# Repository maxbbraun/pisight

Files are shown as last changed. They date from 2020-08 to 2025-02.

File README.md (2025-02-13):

# PiSight

I put a Raspberry Pi inside an Apple iSight. You can read more about the PiSight [on Medium](https://pisight.camera).

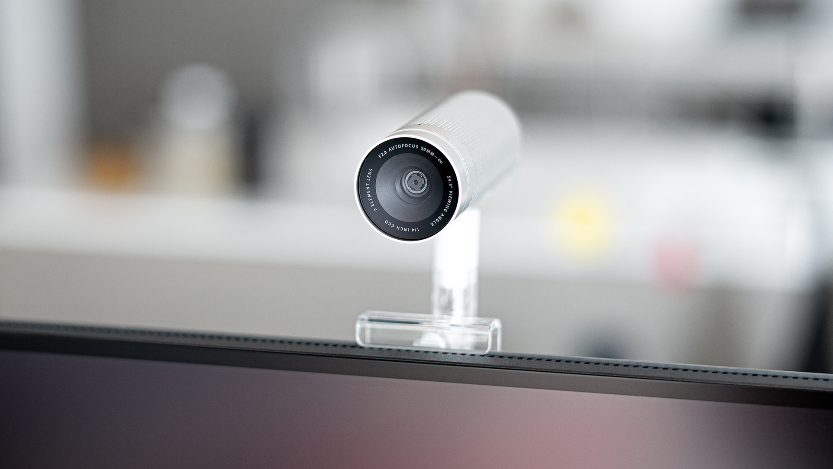
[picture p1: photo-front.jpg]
PiSight photo front view


## Hardware

| Part | Info | Price (2020) |
| :- | :- | -: |
| [Apple iSight](http://www.minimallyminimal.com/blog/apple-isight) | Available new and used on eBay | [$15 to 150](https://www.ebay.com/sch/i.html?_nkw=Apple+iSight) |
| [Raspberry Pi Zero](https://www.raspberrypi.org/products/raspberry-pi-zero/) | The [W](https://www.raspberrypi.org/products/raspberry-pi-zero-w/) version adds Wifi, which makes working with it easier and opens it up to more applications | [$5](https://www.adafruit.com/product/2885) or [$10](https://www.adafruit.com/product/3400) |
| [Raspberry Pi Camera V2](https://www.raspberrypi.org/products/camera-module-v2/) | Supports 1080p@30 or 720p@60, at a 62° horizontal field of view | [$29.95](https://www.adafruit.com/product/3099) |
| M2.6 screws | 4 of M2.6 x 0.45 mm Thread, 6 mm long | [$9.26 for 25](https://www.mcmaster.com/91290A073/) |
| M2 screws | 2 of M2 x 0.4 mm Thread, 4 mm long | [$13.28 for 100](https://www.mcmaster.com/91290A011/) |
| O-ring | Covers the gap around the lens | [$6.16 for 50](https://www.mcmaster.com/9262K562/) |
| Raspberry Pi Zero camera cable | A few options, but the 15 cm long narrow ones seem to work best | [$3.49](https://www.waveshare.com/raspberry-pi-zero-v1.3-camera-cable.htm) |
| Micro-USB cable | Many options, just need to fit the iSight adapter | [$8.99](https://www.amazon.com/Anker-Powerline-Micro-USB-Smartphones/dp/B012VZT5IO/) |
| 3D-printed frame | Use [`PiSight.stl`](PiSight.stl) or [`PiSight.step`](PiSight.step), dimensions in mm, cost varies significantly depending on material quality | [$50 to $200](https://www.fictiv.com) |

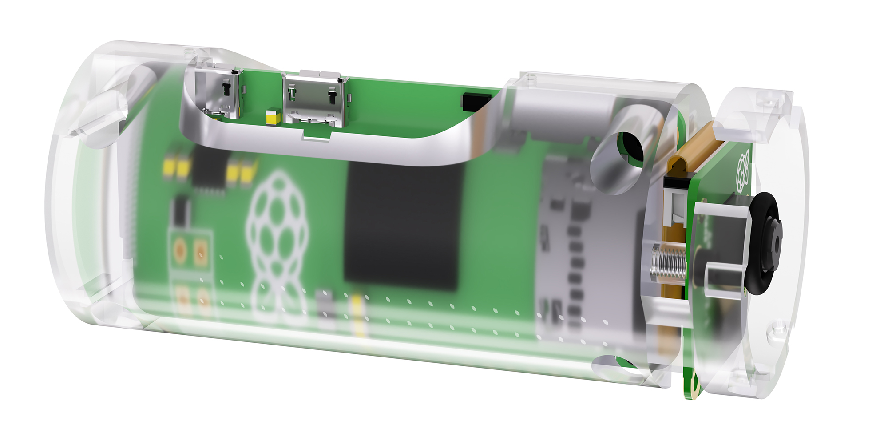
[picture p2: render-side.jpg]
PiSight rendered side view


## Software

The PiSight camera implements the [UVC standard](https://en.wikipedia.org/wiki/USB_video_device_class) via the [Gadget API](https://www.kernel.org/doc/html/latest/driver-api/usb/gadget.html), which turns the Raspberry Pi and camera into a plug-and-play USB webcam.

Simply install [Raspberry Pi OS](https://www.raspberrypi.org/downloads/raspberry-pi-os/) (the Lite version is enough) and then run:

```bash
git clone https://github.com/maxbbraun/pisight
cd pisight
sudo ./setup.sh
```

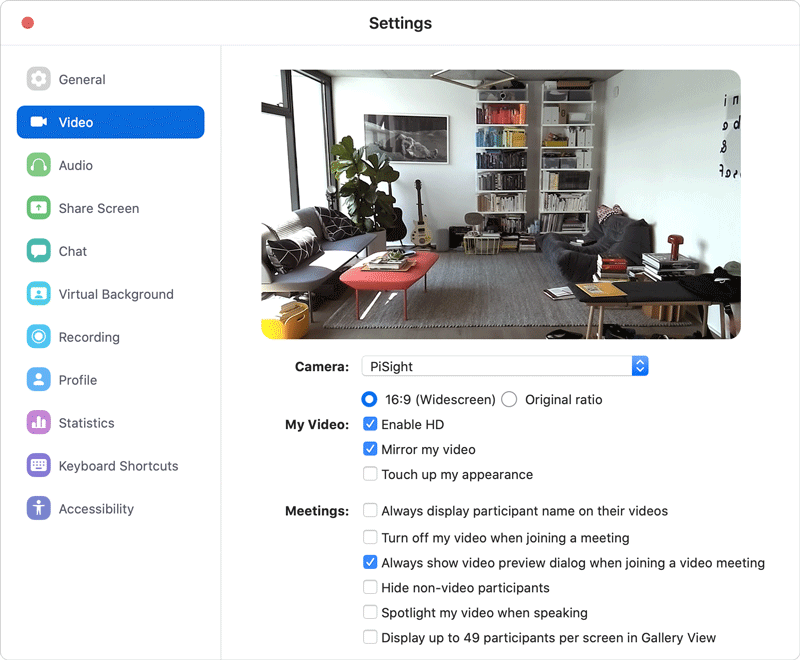
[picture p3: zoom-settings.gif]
PiSight in Zoom settings


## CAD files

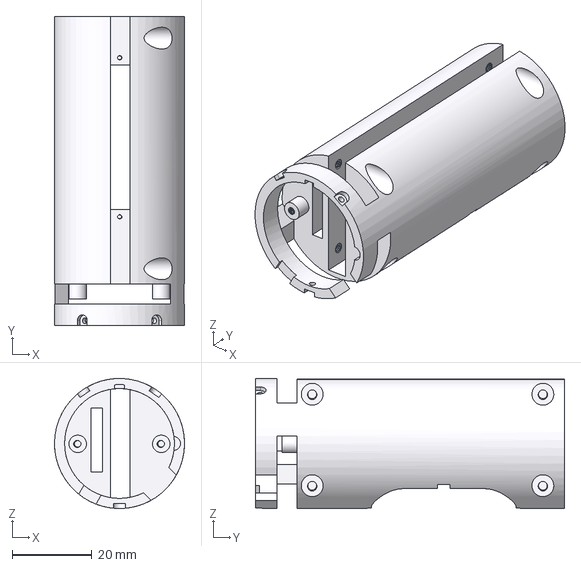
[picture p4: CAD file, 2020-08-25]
PiSight.step
32.7 x 77.7 x 32.7 mm

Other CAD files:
PiSight.stl

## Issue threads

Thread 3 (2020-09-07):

MacBook Pro not detecting Raspberry Pi Zero W

Wthebinder, 2020-09-07:
Thank you so much for making this, I have always wanted to resurrect my iSight Camera!

I have started to order the parts for this project and I am at the point where I can start installing the software. I have both a Raspberry Pi Zero W and a Raspberry Pi Camera Module v2 (and a micro-sd card too). I also have the Anker Micro-USB cord too.

I started the software part of this project by installing Raspbian and followed the installation instructions via SSH over a Micro-USB Ethernet Adapter. I also connected it to my WiFi network too. After I finished all of the installation steps, I plugged it into my 2017 MacBook Pro 15" running MacOS Catalina (10.15.6). My MBP didn't detect it, even in a "System Report".

I have tried troubleshooting by doing the following:
- Using the Anker Micro-USB cord with an Android Phone and my MBP. It worked.
- Taking pictures with my Raspberry Pi Zero W over SSH.
- Trying different Raspberry Pi Zero Ws.
- Reinstalling the software on my Pis.
- Different Micro-SD Cards

I am not sure how to proceed as I couldn't find anything online. This is my first Raspberry Pi Project so I am sorry if there is something obvious that I am missing.

maxbbraun, 2020-09-07:
What do you see when you run `system_profiler SPUSBDataType`? You might want to give it a few seconds to boot first. It should show something like this:

```
$ system_profiler SPUSBDataType
USB:

    USB 3.1 Bus:

      Host Controller Driver: AppleUSBXHCITR
      PCI Device ID: 0x15ec
      PCI Revision ID: 0x0006
      PCI Vendor ID: 0x8086
      Bus Number: 0x00

    USB 3.1 Bus:

      Host Controller Driver: AppleIntelCNLUSBXHCI
      PCI Device ID: 0xa36d
      PCI Revision ID: 0x0010
      PCI Vendor ID: 0x8086

        FaceTime HD Camera (Built-in):

          Product ID: 0x8511
          Vendor ID: 0x05ac (Apple Inc.)
          Version: 72.52
          Serial Number: CCG909704RWH34FFE
          Speed: Up to 480 Mb/s
          Manufacturer: Apple Inc.
          Location ID: 0x14600000 / 46
          Current Available (mA): 500
          Current Required (mA): 500
          Extra Operating Current (mA): 0
          Built-In: Yes

        PiSight:

          Product ID: 0xdead
          Vendor ID: 0x05ac (Apple Inc.)
          Version: 0.01
          Serial Number: 100000000d2386db
          Speed: Up to 480 Mb/s
          Manufacturer: Apple
          Location ID: 0x14300000 / 55
          Current Available (mA): 500
          Extra Operating Current (mA): 0

```

I usually test with QuickTime, which seems to be the most resilient video preview (rather than Photo Booth, for example, which sometimes doesn't work with the camera). Go to File > New Movie Recording and then select PiSight from the dropdown next to the red record button. That should show a video preview from the PiSight.

If none or only one of these works, it might be a clue.

Wthebinder, 2020-09-08:
Thanks for your reply! Unfortunately, the raspberry pi doesn't show up when I do _system_profiler SPUSBDataType_.

maxbbraun, 2020-09-09:
Did you try the other USB ports? Which USB version shows up for the bus?

Wthebinder, 2020-09-09:
Thanks for your reply!

I have tried all 4 of my USB-C Ports using a handful of known good USB-C to USB-A adapters, to no luck. (I waited until I can SSH into it over WiFi, which tells me when it is done booting.) I used the same micro-USB cord earlier today to get some pictures off of an android device. My MacBook Pro has four USB 3.1 Buses.

Could it because I am using a different version of macOS?

maxbbraun, 2020-09-13:
Not sure. Maybe [this](https://medium.com/@kabutosan/so-after-two-days-of-troubleshooting-i-have-identified-to-main-issues-ae46ef05350) is helpful?

Wthebinder, 2020-09-15:
Hmmm, maybe it is my micro-usb cable? Is the one listed on here known to work for this project?

maxbbraun, 2020-09-15:
Yes, the one listed works for me.

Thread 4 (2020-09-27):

Assembly difficulties

John-K, 2020-09-27:
Can you share any photos or experiences from your assembly?

Assembly issues:
1. I can't figure out how to install the camera module in the top of the print, even without the flex attached. It seems like the camera sensor housing is meant to slip through the gap in the ring, but the screw bosses interfere with components on the bottom of the camera board.
2. Does your "Apple medallion" fit in place at the back? The camera flex appears to block it as it needs an extra bit of room to do a 90 degree bend.

Things that work well:
1. The RPiZero fits in nicely and the screws hold it neatly in place.
2. The Front lens assembly fits snugly into the camera ring and the iris actuates nicely.

maxbbraun, 2020-09-27:
Glad to hear you're trying it out!

> I can't figure out how to install the camera module in the top of the print, even without the flex attached. It seems like the camera sensor housing is meant to slip through the gap in the ring, but the screw bosses interfere with components on the bottom of the camera board.

Getting the camera in is definitely the trickiest part. I ended up having to bend the front ring a bit and push the camera through. Definitely test the camera after that to make sure it hasn't been damaged. This is obviously not a great solution, so I've been playing with a version of the model that makes the front ring just a little narrower to give the camera enough room to be inserted, but that isn't ready yet. You could try filing off some material to achieve the same effect.

> Does your "Apple medallion" fit in place at the back? The camera flex appears to block it as it needs an extra bit of room to do a 90 degree bend.

That had worked for me, although I did have to bend the camera flex very tightly.

John-K, 2020-09-28:
I was able to finally get the camera module installed by snipping off the top-left corner of the camera PCB where the mounting hole is in the PCB and then by pushing a fair bit on the ring.

cooperpellaton, 2020-10-16:
I tried installing the camera today.

Clearance is _really_ snug. Managed to break one of the SMDs near the cable mounting point which subsequently broke the camera. I ordered the same print material/resolution from Fictiv as @maxbbraun and found that there is a decent amount of play in the upper ring. In my second attempt, I'll try to flex the edge rather than come at it from the side (90°) approach.

On the positive side, the fit of the rest of the components is perfect. Was a bit difficult to get the ribbon cable into the recess but now that it's in there it's not going anywhere.

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

Lastly, a word of warning - the screws on the _inside_ assembly: the frame attachment of the black plastic, are _really_ tight. It stripped the bit I was using!

moorlag, 2024-02-13:
Can you share a routing overview of the flex cable?

maxbbraun, 2024-02-13:
It's been a while since I last did this, but maybe these pictures help. The flex cable is folded diagonally behind the camera.

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

moorlag, 2024-02-13:
wow thanks @Max Braun!
Happy that I have a few cables to get it right.

It's such a fun project :-) thanks again!

maxbbraun, 2024-02-13:
I'm glad you're enjoying it! :)

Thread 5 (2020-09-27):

Field of view issues

samnunn, 2020-09-27:
Hi Max!

Awesome project mate. I've bought a second-hand iSight and I'm in the throes of recreating this setup for myself. One question though: why did you switch down to 720p?

I used Dave's original 1080 setup and I noticed that the field of view was quiet a lot narrower than expected. Is this related? I haven't actually gotten your fork working yet, so I'm yet to compare the pair.

Many thanks.

Sam

maxbbraun, 2020-09-27:
Hi Sam!

Yeah, I had some issues with the uvc-gadget implementation and I think field of view was part of it. Overall, it felt like the code was written for 720p anyway (e.g. [this](https://github.com/climberhunt/uvc-gadget/blob/3d1e49e420fd2359cf95e170336144189eaaad06/uvc-gadget.c#L2047)) so I reverted it to that and never got back to trying to get 1080p or more to work. I'm not sure if anything would be fundamentally in the way of that though.

Let me know how it goes!
Max

John-K, 2020-09-28:
Per https://www.raspberrypi.org/documentation/raspbian/applications/camera.md the Camera Module
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
It would appear that 1640x922 would be the sweet-spot with full FOV and 2x2 pixel binning.

samnunn, 2020-10-02:
Awesome notes folks! I'm a little lost about how I would implement 1640x922 successfully, though. Any pointers?

iliesaya, 2020-10-12:
I agree that it would be nice to have the full field of view of the camera

muffinresearch, 2021-01-08:
I had similar issues with zoom randomly switching to a higher resolution (which showed as very zoomed in) during conf calls using [showmewebcam](https://github.com/showmewebcam/showmewebcam) v1.70. [Following some helpful directions from @htruong who mentioned a way of enabling github actions on the fork to enable image builds there, I patched the list of available resolutions to fix it to 1280x720 here](https://github.com/muffinresearch/showmewebcam/pull/1). The built images from that PR are available by clicking details on the relevant build and looking at the artifacts dropdown. Hopefully at some point more control for resolutions will be exposed to users without the need to create a new image restricting resolutions.

FWIW: I found getting the sd card out to re-flash it was possible without removing the camera module by unscrewing the zero and carefully hinging the sd card end to be able to get to it. At some point showmewebcam will probably facilitate updates via usb. See https://github.com/showmewebcam/showmewebcam/issues/54

rickyktan, 2021-08-15:
> I had similar issues with zoom randomly switching to a higher resolution (which showed as very zoomed in) during conf calls using [showmewebcam](https://github.com/showmewebcam/showmewebcam) v1.70. [Following some helpful directions from @htruong who mentioned a way of enabling github actions on the fork to enable image builds there, I patched the list of available resolutions to fix it to 1280x720 here](https://github.com/muffinresearch/showmewebcam/pull/1). The built images from that PR are available by clicking details on the relevant build and looking at the artifacts dropdown. Hopefully at some point more control for resolutions will be exposed to users without the need to create a new image restricting resolutions.
>
> FWIW: I found getting the sd card out to re-flash it was possible without removing the camera module by unscrewing the zero and carefully hinging the sd card end to be able to get to it. At some point showmewebcam will probably facilitate updates via usb. See [showmewebcam/showmewebcam#54](https://github.com/showmewebcam/showmewebcam/issues/54)

@muffinresearch I have tried to rebuild the showmewebcam using the same resolution restrictions as you (1280x720), but have run into multiple bumps. Are you able to share the built images again? The artifacts in your pull request have expired, and one can't download the images anymore.

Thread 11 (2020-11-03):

Completed Build

cooperpellaton, 2020-11-03:
Not sure where to put feedback/comments. Maybe a feedback section in the wiki?

# Overview
On balance, this went well. I'd recommend purchasing at least 2x the number of ribbon cables you anticipate since they're extremely easy to puncture when working the excess into the case-area recess. Further, I think V2 of the model could do away with the strut supporting the upper ring on the (looking directly-on) left-hand side. There's enough flex in the print that without it you can easily slip the camera underneath. In terms of camera-module sizing, I found nail clippers work extremely well. I found a pair with a curved blade that allowed me to match the corner of the camera module PCB to the case housing.

Total time (including a re-order of camera module + ribbon cables after breakage) was 4 weeks from inception to completion.

# Glamour Shots
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

maxbbraun, 2020-11-05:
Very cool. Thank you for sharing, Cooper!

tillycatcat, 2020-12-20:
Hey @cooperpellaton - I'm just about to send the print to the chap with a 3d printer to print. You mentioned the strut (and I'm a complete beginner here). Is it possible to send a picture/a model file of what you mean?! I'll definitely give it a go!

Thanks
Geoff.

cooperpellaton, 2020-12-22:
@tillycatcat if you look in the 3D print where the camera module should go there are 2 struts that support the upper ring. If, looking head one, you remove the _left_ strut, the structural integrity should be fine **and** you should be able to get the camera inside more easily.

grantland, 2021-02-23:
I'm in the process of building one myself and have noticed that the ribbon cable pokes out the back where the original white cap with the Apple logo is supposed to go. Is it safe to bend the cable to get the cap on or did you leave it without the cap on?

maxbbraun, 2021-02-28:
@grantland I had to bend the cable very close to the connector, which isn't ideal, but doesn't seem to have caused any issues so far.

cooperpellaton, 2021-02-28:
@grantland I used [this](https://www.waveshare.com/raspberry-pi-zero-v1.3-camera-cable.htm) cable and had no problems with it being too long. It did, however, have to bent in order for it to fit into the printed recess.

tillycatcat, 2021-03-02:
I've gone through a few cables now trying to figure out the exact point where to bend it. I wonder if the cable will withstand a fold?

cooperpellaton, 2021-03-03:
I punctured one cable when bending but that was due to applying too much force with a pair of tweezers. I think as long as you don't overly force it then there won't be any problems.

tillycatcat, 2021-03-14:
I'm going to have another crack at this soon. Has anyone got a picture of the bend at the camera module?

austriker27, 2021-11-11:
Looks stunning! @cooperpellaton I'm curious, I'm curious about buying a completed build - would you be interested in building one and selling it?

cooperpellaton, 2021-11-16:
@austriker27 I'd be open to doing it, however, I'd caution you that the cost will likely be prohibitively expensive. Do feel free to email me.

austriker27, 2021-11-17:
@cooperpellaton yeah i figure it won't be cheap but I'm still curious. What's your email?

cooperpellaton, 2021-11-17:
@austriker27 see my website linked in my bio.

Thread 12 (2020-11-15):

FDM Printing?

mattkerrison, 2020-11-15:
I've bought a used iSight & have the Raspberry pi lying around, but I was curious if anyone has tried to print the enclosure with an FDM printer?
With a 0.2mm nozzle I'd think it would likely be possible, curious as I would prefer that than ordering a resin printed piece.

phenomeus, 2020-12-15:
same for me and also I bought an ender 3 v2 and will try to print this. right now I play around with Cura slicer. will report asap, but right now I have too much projects going on in parallel

stockHuman, 2021-01-26:
_Just_ finished completing this project, printed this on an Ender 3.

I had to omit the tiny fasteners due to the very tight tolerances needed around the shutter assembly & the two anchoring points to the cylindrical case. It's effectively friction-fit, but that works rather well. A dremel comes in handy.
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

phenomeus, 2021-01-26:
what settings on the ender? standing upright?

what adhesion setup? skirt? brim? raft?

infill? suport?

so many questions :D I will do it on my ender 3 v2 asap, but I still have so many projects going on

stockHuman, 2021-01-28:
@phenomeus

That's right, standing tall, printed with the camera-insert side touching the build plate. I did this to minimize supports, which were a pain to remove.

Simple skirt around the print, no special adhesion settings. And I believe 14% infill (gyro), nearly default (Cura HQ) settings otherwise. No part cooling fan, but that's specific to my machine.

Good luck on your print. The real pain was assembly!

phenomeus, 2021-03-31:
finally I got it printed on my ender 3 v2 with 10% support that I had to pull off. see pictures, everything went fine
but I had the camera side pointing to the top.

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

msgilligan, 2021-03-31:
> with 10% support that I had to pull off. see pictures

Do you have any photos with the support still attached? I'd be curious to see what it looked like at that point.

My Ender 3 V2 is supposed to arrive today and I am new to 3D printing, but this is one of the first projects I'm going to try.

phenomeus, 2021-03-31:
sorry I don't but here you can see the green "helpers" = support that I had to remove

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

msgilligan, 2021-03-31:
@phenomeus Thanks!

phenomeus, 2021-03-31:
your welcome, here you can see my finished build https://github.com/maxbbraun/pisight/issues/16

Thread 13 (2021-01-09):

Activity LED using the original iSight LED

muffinresearch, 2021-01-09:
Thanks for the excellent project. After getting a build working I've been playing around with adding an LED to show when the camera is active.

[Showmewebcam handily switches GPIO 21 to `HIGH` when the camera is in-use](https://github.com/showmewebcam/showmewebcam#led-indicator) so it's possible to put an LED in the place of the one that would have been on the original iSight.

All that's required is a 330ohm resistor and an LED. As seen in this test run:

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

I pulled out the original LED from the iSight and carefully soldered two cables either side of the surface mount LED. I used some shrinkwrap to shield the connections from the case and used shrinkwrap with a hole punched in it to aim to get the light only going up into the small clear plastic diffuser. A small amount of rearwards leakage was fixed with some Aluminum tape on the body.

Here's the end result:

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

maxbbraun, 2021-01-10:
Very cool!

grantland, 2021-02-23:
@muffinresearch Super cool! Does the original LED need a 330ohm resistor too or was it just plug and play?

muffinresearch, 2021-02-23:
> @muffinresearch Super cool! Does the original LED need a 330ohm resistor too or was it just plug and play?

Yep, I added the same size resistor with the original led too.

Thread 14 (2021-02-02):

Camera Module V2.1

leonardofaria, 2021-02-02:
Has anyone used [this camera](https://www.amazon.ca/Raspberry-Camera-Official-8-Megapixel-LABISTS/dp/B07W921DCT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) model for their pisight project?

I am going to start mine and I'm wondering if there is any major difference between this one and the one reported in the [README](https://www.raspberrypi.org/products/camera-module-v2/)

phenomeus, 2021-04-01:
i have the 2.1 but not the noir version #16

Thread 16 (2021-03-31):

my Build with own USB Adapter .stl

phenomeus, 2021-03-31:
thank you for this project, I finally finished this project after 4 months ;)

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
even with the (sadly not original) LED anymore.

build diary
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
printed

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
had to slice here, a corner was in the way

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
original LED, somehow I killed it later, so I had to use a very big and "normal" LED that I had to hone down from both sides

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
this is where the LED can be stored

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
how to store the flex cable

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
alternative LED with 330 resistor (< you need this)

my used iSight camera had no firewire adapter anymore, so I modeled with blender my own for USB (in my case I used a micro usb to usb-c amazon basics cable, an amazon kindle usb cable worked here also, pretty standard size)

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
mark 1 without the support on both sides

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
mark 2 with supports to stabilize the camera

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
done :) thank you for watching

here is the download for .stl and .blend file

[pisight_usb_adapter.zip](https://github.com/maxbbraun/pisight/files/6239243/pisight_usb_adapter.zip)

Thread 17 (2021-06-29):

New Dell webcam might be a perfect fit for PiSight

realph, 2021-06-29:
Dell just announced a [new 4K webcam](https://www.tomshardware.com/uk/reviews/dell-ultrasharp-webcam) that is heavily inspired by the original iSight design. The good news is we may be able to fit this camera module inside of an iSight body. The bad news is the casing on the Dell webcam seems to be bigger than that of the iSight...

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

I've never really done any hardware hacks before. Is this a simple case of pulling out the Dell camera module and seeing it if fits inside the iSight tube? If It does I assume we'll need to also need to make sure there's enough room for a 3D printed frame like Max's original design so it fits snug.

Does anyone have any additional advice on how to go about this? I may try and pick one of these webcams up over the weekend and tinker around with it to verify if it fits.

realph, 2021-06-29:
Hmm it looks like the board touches the edges of the anodised frame so it can't be much smaller than 420mm, which means it won't fit inside the iSight body. 😢

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

mattkerrison, 2021-06-29:
Nice idea but I think @realph is right

cwelsh1812, 2021-06-30:
Think you have an extra '0' on the measurements, otherwise that is one BIG webcam !

Would be great if it fitted but the search continues I think.

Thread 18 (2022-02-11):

Completed build

rknightuk, 2022-02-11:
It was useful to see everyone else's completed builds here when I was doing mine so I figured I'd add mine too (I even used @phenomeus adaptor as well).

Blog post: https://rknight.me/building-a-pisight/

The printed casing:

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

The finished product:

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

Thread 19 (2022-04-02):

Script doesn't work with Raspberry pi zero 2 w

Emstr, 2022-04-02:
Hey Max. Big fan.

I'm working on this project and can only get my hands on a pi zero 2 w, rather than the original. Unfortunately when I use your script, the camera feed shows up for half a second, and then the camera becomes unresponsive. Unfortunately showmewebcam hasn't yet added support for zero 2 w. I wonder if you have any ideas?

maxbbraun, 2022-04-02:
Hm, I don't have a Pi Zero 2 W to check. Did you ask over at [showmewebcam](https://github.com/showmewebcam/showmewebcam/issues) yet?

Emstr, 2022-04-03:
Yep – looks like they are working on support but it's not ready yet :(

Yours seems like it works better for me, but then seems to crash. Is there any kind of gpu/memory setting I could try to tweak?

maxbbraun, 2022-04-04:
If they're already working on it, that's probably your best bet!

moorlag, 2024-02-13:
I've found a solution using the FULL install and not the remote only.
Some how it does work with a full installation of the OS.

olm3ca, 2024-11-16:
> I've found a solution using the FULL install and not the remote only. Some how it does work with a full installation of the OS.

Could you clarify which full install you used, @moorlag ? 64 or 32 bit, Legacy or regular? Thanks

vguttmann, 2025-01-25:
I've made a working script and PR to this repo, in case anyone is still interested

maxbbraun, 2025-01-26:
@vguttmann's PR is https://github.com/maxbbraun/pisight/pull/25, for anyone who wants to follow along.

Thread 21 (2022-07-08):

Build and modifications (pivot joint, model optimization for mSLA resin printers)

jil24, 2022-07-08:
I initially had built this using the original plans, but found I could not reliably get the camera cable to bend enough to close the case without breaking the cable. Also, the original 3D geometry had extremely tight tolerances (hard to insert the camera board) and was very challenging to print on consumer grade mSLA resin printers like mine due to many unsupported overhangs. I also really wanted that nice pivot joint from the original iSight back. Starting from the original housing model, I modified the plans.

### Changes
1. Changed the Pi board’s position and orientation (slightly tilted) to make more room for cable routing and closing the rear end of the case.
2. Split the housing into two pieces: the front end that holds the lens cover/cap is now separate and held on with screws. This makes it much easier to install the camera board.
3. Added a pivoting hinge. This and the board position changes make the built-in micro-USB port inaccessible so i added a separate port to the bottom of the hinge joint and soldered its connections to the USB test pads on the Pi.
4. Skeletonized much of the housing. It doesn’t need to be particularly strong since it's not handled much. I think this also might make it cheaper to print commercially, but I don’t know.

### My Assembly Steps:
1. Strip iSight for casing and original status LED
2. Solder connection wires to LED, resistor, and Pi I/O pads #13
4. Solder connection wires to micro-usb plug and test points on Pi. These connections will be pretty fragile.
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

5. Mount board in housing, screw in. Add micro SD card. Bend wires to position LED. Route micro-usb wires and plug down into pivoting connector.
6. Snap in and screw down pivoting connector into main housing (M2x6mm screws):
 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

8. Mount camera board like in original plans
9. Mount and screw in the lens cap mounting ring (M2 screws). This is fragile, do not overtighten. If the screw caps protrude too far over to the outside or inside of the ring, sand/file them down to flush.
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

11. Connect up camera board and Pi, gently fold excess cable. You will still need to bend the cable close to the Pi end almost 90 degrees. It’s best to do this while bracing the contacts between pages of a book or something to avoid damaging the contact surfaces, which don’t like bending. Only bend it once if possible and have extra camera cables on hand because I went through 3 camera cables before I got this to work.
12. Test the camera, make sure everything works.
13. Slide assembled housing into case. Add lens cap/cover with very gentle wiggling. I was not able to get the rear cover to snap on, so I used double sided foam tape to hold it on.
15. Plug it in, wiggle the connector onto your choice of stand:
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

STL files for the main housing, the lens cap mount, and the pivoting connector are attached.
I sourced the micro-usb female plug here: https://www.amazon.com/dp/B01A6M86YI
[STLs.zip](https://github.com/maxbbraun/pisight/files/9068293/STLs.zip)

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

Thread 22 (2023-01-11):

Camera Module v3 support

acketon, 2023-01-11:
The v3 Camera Module that was recently released looks like a potential upgrade opportunity. Has anyone attempted to use it yet?

acketon, 2023-01-11:
https://www.raspberrypi.com/products/camera-module-3/

applecuckoo, 2023-04-01:
@acketon @maxbbraun the people at Raspberry Pi upgraded the project themselves, check it out [here](https://www.raspberrypi.com/news/how-to-build-your-own-raspberry-pi-webcam/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)

acketon, 2023-07-11:
I tried the tutorial above but the performance on a Raspberry PI Zero W (1st gen) is choppy and unusable video. I haven't been able to get a Pi Zero 2 due to shortages. I'm not sure if there is a way to improve the performance... its very different than my other PiSight setup using the Pi Zero 1 w/Camera Module 2. But they are also using different software and setup approaches so I'm not sure if that is part of the issue.

It looks like the ShowMeWebCam project doesn't yet have support for Camera Module 3 yet.

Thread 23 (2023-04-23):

Does the shutter mechanism still work with this mod?

foxnoodles, 2023-04-23:
Pretty much the title ^
I was not able to verify it via photos in this guide

maxbbraun, 2023-05-17:
> Does the shutter mechanism still work with this mod?

I started looking into this initially. There is a sensor that could be connected to the Raspberry Pi to read the status of the iris. Hooking that up to do interesting things in software should be quite easy. E.g. it could launch a particular app when you open it. I couldn't quite reverse-engineer the sensor type, so I put it aside for now.

It would be a cool project for someone to pick up. In case someone does, I uploaded a work-in-progress modified 3D model [here](https://github.com/maxbbraun/pisight/files/11493118/PiSight-mod.stl.zip) that carves out an attachment for [one of these](https://www.adafruit.com/product/334) and room for wires to connect the flex cable of the iris sensor to the Raspberry Pi GPIO pins.

> Also what about an Audio?

I haven't looked into it, but audio should be doable. There's still quite a bit of room in the frame that could be used for a microphone. There's some discussion about the software part of this [here](https://github.com/showmewebcam/showmewebcam/issues/43).

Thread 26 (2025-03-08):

How can I have the PiSight show up as "PiSight" on host device?

elcalzado, 2025-03-08:
It shows up as "UVC Camera" on my Windows 11 PC and I want to change what the name of it is. I can't figure out how to. The only place I found "UVC Camera" mentioned was in /sys/kernel/config/usb_gadget/g1/functions/function_name and some other directory within usb_gadget/ but those files seem to not be editable. I've gone through the uvc_gadget's repo and can't find a mention of "UVC Camera". Is my PC just choosing to name it that?

I changed this from the script on the tutorial hoping it would change the name but it did not.
CONFIGFS="/sys/kernel/config"
GADGET="$CONFIGFS/usb_gadget"
VID="0x05ac"
PID="0xdead"
SERIAL="0123456789"
MANUF="Apple Pi"
PRODUCT="PiSight"
BOARD=$(strings /proc/device-tree/model)
UDC=\ls /sys/class/udc` # will identify the 'first' UDC`

maxbbraun, 2025-03-09:
It's odd, because the custom name is being set by the script. I can't test it out on Windows, unfortunately.

elcalzado, 2025-03-09:
That's what I thought.. I can't test it on Mac until tomorrow. From what you know though, is the PRODUCT variable all that needs to be changed to make it show up as something? If so, is it most likely an issue with how Windows is detecting it? I'll leave a [picture](https://imgur.com/a/bQ3MGUq) of the info I see on Device Manager for the camera.

elcalzado, 2025-03-21:
In case anyone is still struggling with this I just figured it out. Not really sure why this works like that but I'll share my findings.

If you add `echo "PiSight" -n  | sudo tee functions/$FUNCTION/function_name` to the script after `mkdir functions/$FUNCTION` it should work!

Seems like by default the linux driver creates a file named function_name with value "UVC Camera". Before, I didn't know how to change this since I would get a "device is using this" or similar error. It seems to be that was because I was trying to do it after the symlink between functions/ and configs/ but I didn't test to make sure.

maxbbraun, 2025-03-23:
Hi @elcalzado! Could you check if you can run the full setup with a patched in PR #27 on a fresh Pi Zero 2 W without any errors? Then we can merge the fix.

elcalzado, 2025-03-24:
Sure! I’ll get it done some day this week but I’ll be away from my PC for a the first few days of the week. I’ll notify when I do it.

Closed 2025-03-21.

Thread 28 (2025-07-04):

Raspberry Pi Zero 2 W

Aesir-code, 2025-07-04:
Trying to run this on a Raspberry Pi Zero 2 W, running Bullseye 32 bit lite and I keep getting Device Descriptor Request Failed.
I've tried building various scripts from various tutorials, still can't get it to work.

Ultimately, I want to feed the video from a file rather than a webcam, so I don't have a camera module plugged in and instead am setting the last line in rpi-uvc-gadget.sh to:
uvc-gadget -d 0 uvc.0 &

I've also tried updating the config with:
dtoverlay=dwc2,dr_mode=peripheral

Any thoughts?

langchou, 2025-07-12:
Hi, is the run failing because of the system? I am planning to run this project using Raspberry Pi Zero 2 W.

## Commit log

2020-08-23 Add 3D model files
    [PiSight.step, PiSight.stl]
2020-08-25 Clean up file name info in STEP file
    [PiSight.step]
2020-10-06 Clarify STL file dimensions
2025-03-23 Fix device name on Windows
    Using the suggested solution from issue #26
2026-05-07 Fix macOS clamshell camera identity
